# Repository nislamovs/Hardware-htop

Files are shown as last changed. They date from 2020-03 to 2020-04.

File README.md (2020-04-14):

# Hardware-htop
Wireless desktop device for visualizing system status.

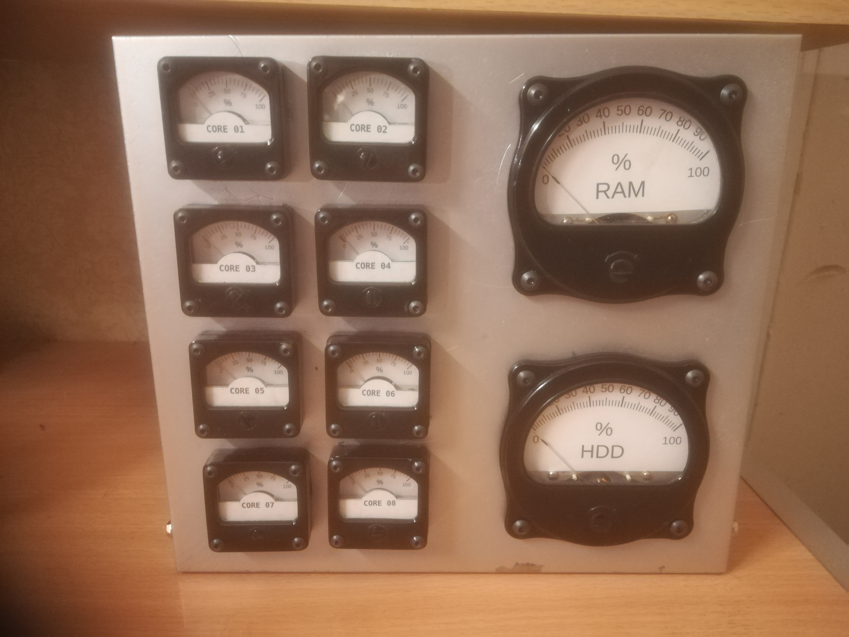
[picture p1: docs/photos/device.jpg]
Device
 <!-- .element height="50%" width="50%" -->

### Summary:

1. [Description](#description)
2. [Linux script setup](#linux-script-setup)
3. [Hardware module schematic](#hardware-module-schematic)
4. [Setting up IDE and flashing firmware](#setting-up-ide-and-flashing-firmware)
5. [Additional sources](#additional-sources)
6. [Starting up and calibration](#starting-up-and-calibration)
7. [Video demonstration](#video-demonstration)
8. [Purpose](#purpose)  

------------------------------------------------------------------------------------------------------------------
### Description:

This device shows load of Your CPU cores, used HDD space in percents and used RAM in percents. It's wireless.
It has it's own web server, where Your OS is sending collected data about itself in JSON format. The project 
works only on Linux systems, however could be adapted to other OS.

The project consists of two parts: **Linux script** and **ESP32 board** with panel meters:

**Linux script** is a script, written in bash - endless loop, that collects data about the system (cpu core load, 
ram and hdd space), builds http request in JSON format and sends it to ESP32 board.

**ESP32 board** is [board][board_wiki] [I've used _Lolin32 lite_ board], with connected to it panel meters. I used old soviet 
ammeters and voltmeters. All of them were connected via resistors to reduce current (for bigger ones I used 50uA 
panel meters, so I needed to use appropriate resistors, like ~60kOhm) and voltage (I used 3v voltmeters, so I needed 
only slightly reduce voltage - I used potentiometers for 250kOhms, connected as voltage dividers).

Device also has reset button, power switch and powerbank to make it fully wireless ;)

[Back](#summary)

------------------------------------------------------------------------------------------------------------------
### Linux script setup:

To make possible to run script on Linux [we are talking about **system_status_report.sh**], it's necessary first to install 
some additional software:

```sudo apt install -y jq sar curl```

Then follow these steps:

- Make the script ```[system_status_report.sh]``` executable:
  - ```chmod a+x system_status_report.sh```

- Copy script to init.d folder:
  - ```sudo cp ./system_status_report.sh /etc/init.d/``` 

- Run command: ```crontab -e``` and add to the end of file the following line:
  - ```@reboot bash /etc/init.d/system_status_report.sh```
  
- Save and exit.  

Done! Now when Linux will start, it'll collect data about cpu, hdd and ram, build request and send it to hardware module. 

P.S. Possibly You will need to fix hardware module ip address. Check Your router settings (DHCP clients).

[Back](#summary)

------------------------------------------------------------------------------------------------------------------
### Hardware module schematic

Few photos:

![Schematic1](docs/photos/schematic1.jpg) <!-- .element height="50%" width="50%" -->

![Schematic2](docs/photos/schematic2.jpg) <!-- .element height="50%" width="50%" -->

![Schematic3](docs/photos/schematic3.jpg) <!-- .element height="50%" width="50%" -->

Schematic with description:

![Schematic4](docs/photos/schematic1_desc.jpg) <!-- .element height="50%" width="50%" -->

1. 1ma panel meter (M4203) - shows core load.
2. 3v panel meter (M4203) - shows core load.
3. 50uA panel meter (M494) - show hdd used space (left) and ram usage (right).
4. Reset switch.
5. Power switch.
6. Powerbank (1 cell).
7. Reset button connector.
8. Power switch connector.
9. Power bank connector.
10. Lolin32 module power connector.
11. Lolin32 module.
12. Two 50kOhm potentiometers ( there are also 10kOhm smd resistors connected in series with them to Lolin board).
13. Two 10kOhm potentiometers for 50uA ammeters, one 5kOhm potentiometer for 1ma ammeter, seven 250kOhm potentiometers 
for 3v voltmeters.   

Panel meters used:

![Panel_meters](docs/panel_meters.jpg) <!-- .element height="50%" width="50%" -->

Gauges:

The gauges for all panel meters could be found in ```front_panel_images``` folder. When you will print them, set scale to 103%.
The gauges were drawn in [Scale Master][scale_master] and exported as PNG with 600 dpi quality.

Circuit diagram:

![circuit_diagram](docs/photos/circuit_diagram.png) <!-- .element height="50%" width="50%" -->

[Back](#summary)

------------------------------------------------------------------------------------------------------------------
### Setting up IDE and flashing firmware:

Before You will flash Your Lolin32 module, You should setup Arduino IDE.

Open Arduino IDE, go to `File -> Preferences`. In `Additional Boards Manager URLs field` write:

`https://dl.espressif.com/dl/package_esp32_index.json, http://arduino.esp8266.com/stable/package_esp8266com_index.json`

![arduino_ide1](docs/arduino_ide.png) <!-- .element height="50%" width="50%" -->

This will add ESP32 boards support.

#### Libraries

To compile the project You need to install additional libraties. Go to Arduino IDE `Library Manager`, and install the 
following libs:

- ArduinoJson

Not all libs You will need You would find in Arduino IDE `Library Manager`.

Open terminal, go to Arduino user libs folder (in Ubuntu it is `$HOME/Arduino/libraries`), and clone there additional libs.
Shortly:

```
cd ~/Arduino/libraries
git clone https://github.com/me-no-dev/AsyncTCP.git
git clone https://github.com/me-no-dev/ESPAsyncWebServer.git
``` 

If You don't have git installed, do it:
```
sudo apt install git
```

Then restart Arduino IDE.

#### Compile and run:

Before the compilation You should change the ssid and password in code to the ssid and password of Your wifi network.

Then select board `[LoLin32 D32]`, select upload speed `[115200 bps]`, set port (e.g. /dev/ttyUSB0), compile and upload. 

[Back](#summary)

------------------------------------------------------------------------------------------------------------------
### Additional sources:

- Lolin32 pinout

![pinout](docs/ESP32_Pinout.png)

Also I recommend You to visit the following sources:

`
https://github.com/me-no-dev/ESPAsyncWebServer
https://arduinojson.org/v6/doc/upgrade/
`

[Back](#summary)

------------------------------------------------------------------------------------------------------------------
### Starting up and calibration:

As You can see, there are 2 files `test_75%_gauge_values.sh` and `test_100%_gauge_values.sh` in project root folder.

When You will launch first time hardware module, You should setup all potentiometers as expected. 

Firstly launch `test_100%_gauge_values.sh` script and set all meter's arrows to 100%. Then terminate script.

After that launch `test_75%_gauge_values.sh` script and set all meter's arrows to 75%. Then also terminate script.

If meters are not reacting, check power supply, ip address, polarity of connections between Lolin and meters. Also You 
could try to push reset button.  

[Back](#summary)

------------------------------------------------------------------------------------------------------------------
### Video demonstration:

https://youtu.be/7kQVsOccEv4 

[Back](#summary)

------------------------------------------------------------------------------------------------------------------
### Purpose:

![Purpose](docs/PURPOSE.JPG)

[Back](#summary)

------------------------------------------------------------------------------------------------------------------

  [board_wiki]: <https://wiki.wemos.cc/products:lolin32:lolin32_lite>
  [scale_master]: <https://soulmare.github.io/scale_master/#>

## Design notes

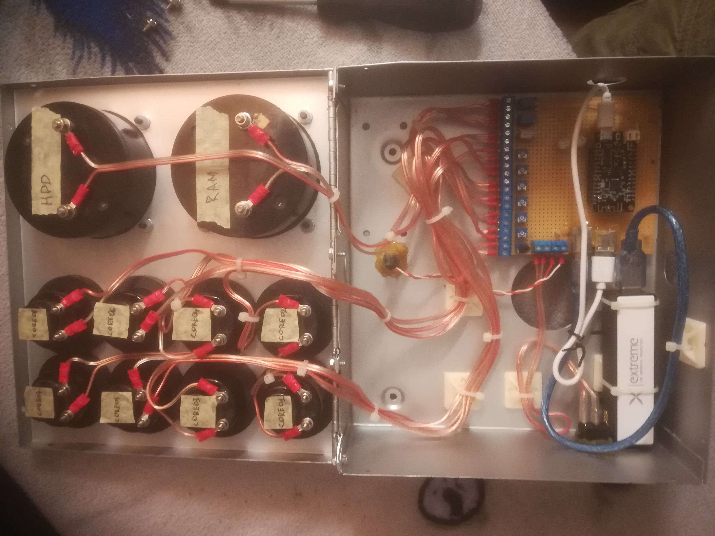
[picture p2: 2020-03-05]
docs/photos/schematic1.jpg

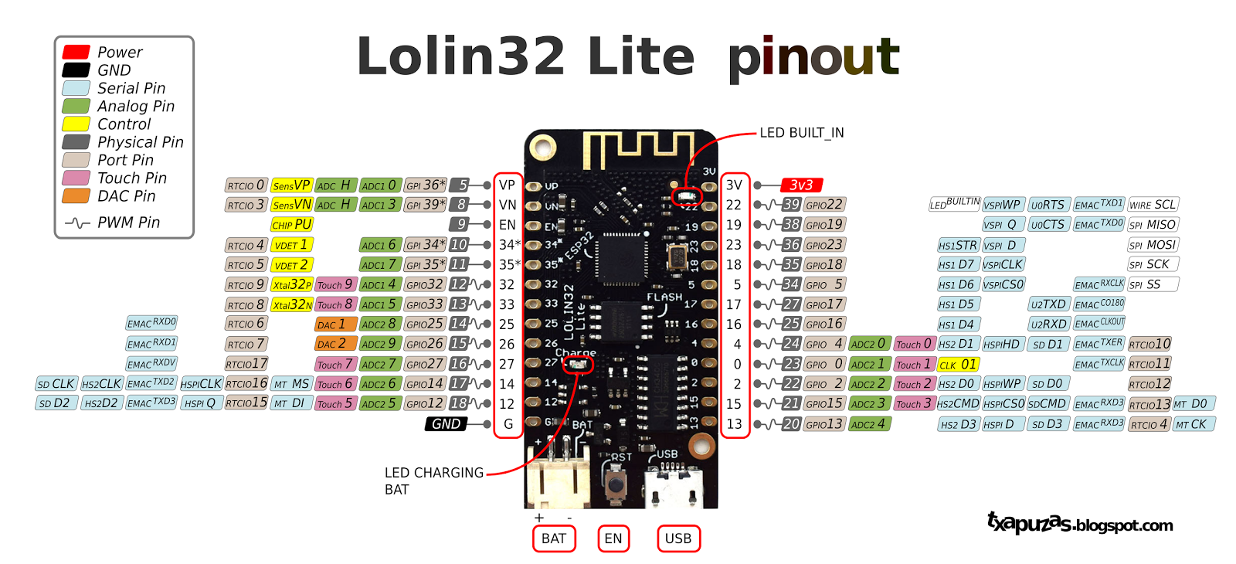
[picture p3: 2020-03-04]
docs/ESP32_Pinout.png

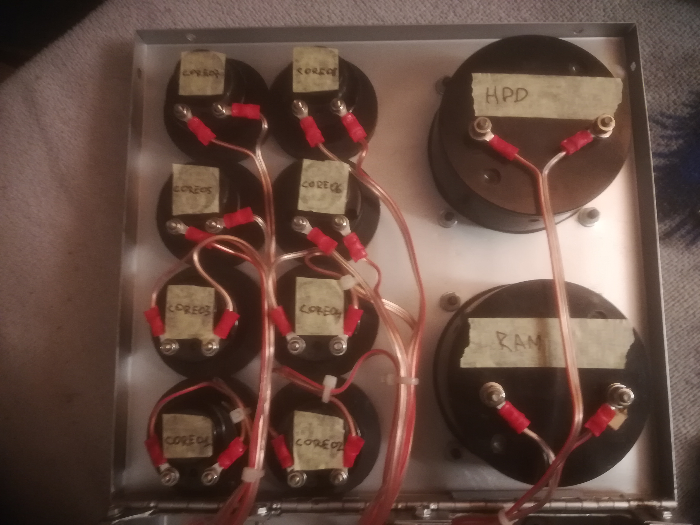
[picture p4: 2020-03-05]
docs/photos/schematic2.jpg

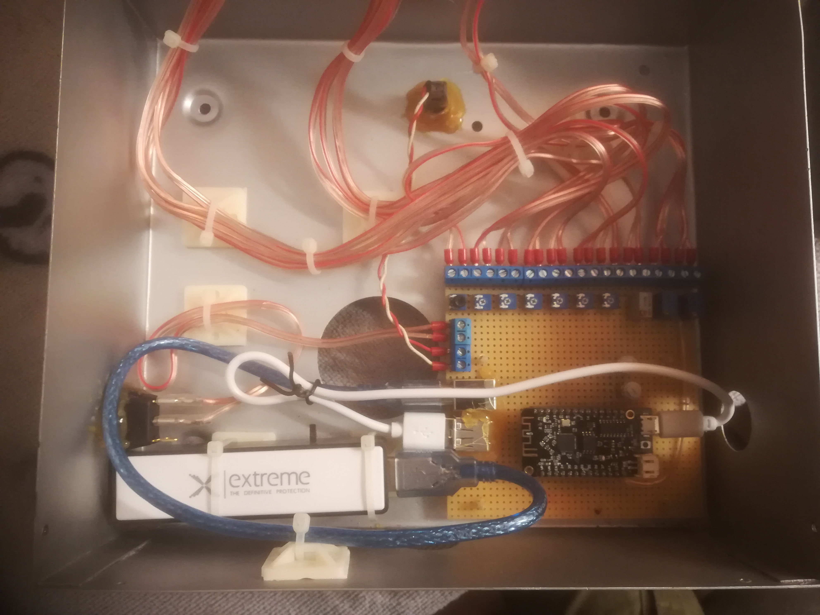
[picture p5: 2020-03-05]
docs/photos/schematic3.jpg

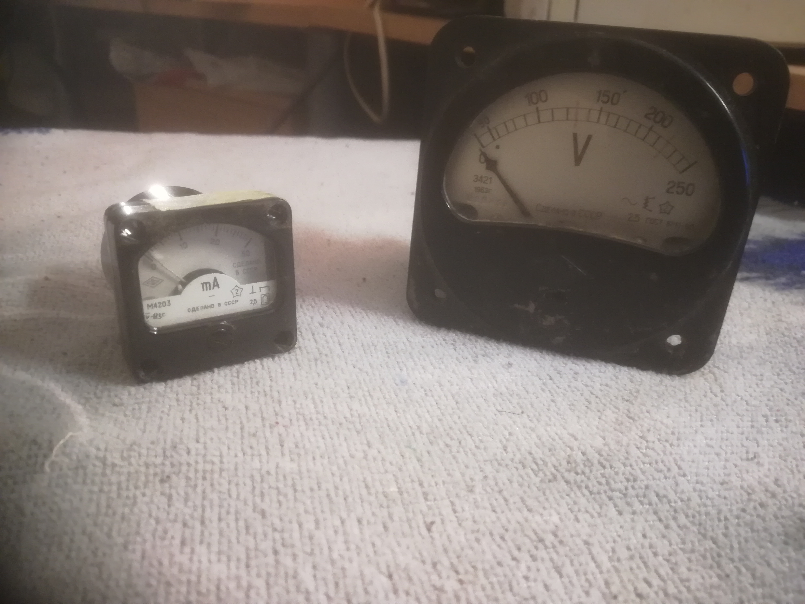
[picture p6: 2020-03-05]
docs/panel_meters.jpg

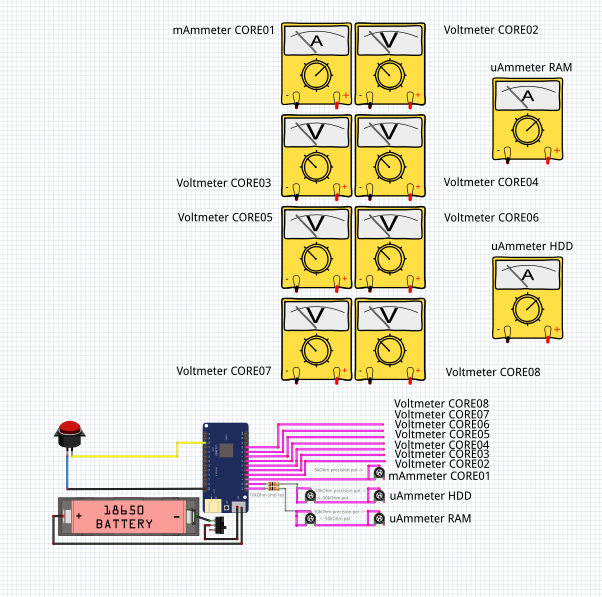
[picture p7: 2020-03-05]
docs/photos/circuit_diagram.png

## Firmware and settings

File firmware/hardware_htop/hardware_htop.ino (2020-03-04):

#include <WiFi.h>
#include "ESPAsyncWebServer.h"
#include "ArduinoJson.h"

#define RAM_Pin 13
#define HDD_Pin 15

#define CORE_01_Pin 2
#define CORE_02_Pin 0
#define CORE_03_Pin 4
#define CORE_04_Pin 16
#define CORE_05_Pin 17
#define CORE_06_Pin 5
#define CORE_07_Pin 18
#define CORE_08_Pin 23

#define BODY_BUFFER_SIZE 1024

 
// SSID & Password
const char* ssid = "*****";         // Enter your SSID here
const char* password = "*******";  //Enter your Password here
 
AsyncWebServer server(80);
 
void setup() {

  ledcAttachPin(RAM_Pin, 0);
  ledcAttachPin(HDD_Pin, 1);
  ledcAttachPin(CORE_01_Pin, 2);
  ledcAttachPin(CORE_02_Pin, 3);
  ledcAttachPin(CORE_03_Pin, 4);
  ledcAttachPin(CORE_04_Pin, 5);
  ledcAttachPin(CORE_05_Pin, 6);
  ledcAttachPin(CORE_06_Pin, 7);
  ledcAttachPin(CORE_07_Pin, 8);
  ledcAttachPin(CORE_08_Pin, 9);

  for(int n = 0; n <= 9; n++) {
    ledcSetup(n, 4000, 8);
    ledcWrite(n, 0);
  }

  Serial.begin(115200);
  WiFi.begin(ssid, password);
 
  while (WiFi.status() != WL_CONNECTED) {
    delay(1000);
    Serial.println("Connecting to WiFi..");
  }
 
  Serial.println(WiFi.localIP());
 
  server.on(
    "/post",
    HTTP_POST,
    [](AsyncWebServerRequest * request){},
    NULL,
    [](AsyncWebServerRequest * request, uint8_t *data, size_t len, size_t index, size_t total) {

      DynamicJsonDocument doc(BODY_BUFFER_SIZE);
      auto error = deserializeJson(doc, data);
      if (error) {
          AsyncWebServerResponse *response = request->beginResponse(500, "text/plain", error.c_str());
          request->send(response);
      }
 
      int core01  = (int)((float)(doc["CORE01"])*(255.0/100.0));
      int core02  = (int)((float)(doc["CORE02"])*(255.0/100.0));
      int core03  = (int)((float)(doc["CORE03"])*(255.0/100.0));
      int core04  = (int)((float)(doc["CORE04"])*(255.0/100.0));
      int core05  = (int)((float)(doc["CORE05"])*(255.0/100.0));
      int core06  = (int)((float)(doc["CORE06"])*(255.0/100.0));
      int core07  = (int)((float)(doc["CORE07"])*(255.0/100.0));
      int core08  = (int)((float)(doc["CORE08"])*(255.0/100.0));
      int memLoad = (int)((float)(doc["MEMORY_LOAD"])*(255.0/100.0));
      int hddLoad = (int)((float)(doc["HDD_LOAD"])*(255.0/100.0));

      Serial.println("-------------------------------");
      Serial.println("CORE01 >> " + String(core01));
      Serial.println("CORE02 >> " + String(core02));
      Serial.println("CORE03 >> " + String(core03));
      Serial.println("CORE04 >> " + String(core04));
      Serial.println("CORE05 >> " + String(core05));
      Serial.println("CORE06 >> " + String(core06));
      Serial.println("CORE07 >> " + String(core07));
      Serial.println("CORE08 >> " + String(core08));
      Serial.println("RAM    >> " + String(memLoad));
      Serial.println("HDD    >> " + String(hddLoad));
      Serial.println("-------------------------------");

      ledcWrite(0, memLoad);
      ledcWrite(1, hddLoad);
      ledcWrite(2, core01);
      ledcWrite(3, core02);
      ledcWrite(4, core03);
      ledcWrite(5, core04);
      ledcWrite(6, core05);
      ledcWrite(7, core06);
      ledcWrite(8, core07);
      ledcWrite(9, core08);
 
      request->send(200);
  });
 
  server.begin();
  
  Serial.println("HTTP server started");
  delay(100); 
}
 
void loop() {}
